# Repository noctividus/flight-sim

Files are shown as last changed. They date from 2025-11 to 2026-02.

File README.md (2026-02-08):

# Glider Joystick (Flight Simulator) — Arduino Firmware

This firmware turns a **SparkFun Pro Micro (ATmega32U4)** into a USB flight simulator HID for elevator, aileron, rudder, air brakes, and wheel brake (digital), plus a few buttons. Analog axes are read via an **ADS1015** I²C ADC to maximize resolution.

## Required Libraries

- **Arduino Joystick Library** (Matthew Heironimus) — exposes HID joystick
  - <https://github.com/MHeironimus/ArduinoJoystickLibrary>
- **SparkFun ADS1015 Arduino Library** — external 12‑bit ADC
  - <https://github.com/sparkfun/SparkFun_ADS1015_Arduino_Library>
- **Encoder** (PJRC) — quadrature encoder for wheel brake
  - <https://www.pjrc.com/teensy/td_libs_Encoder.html>
- **Wire** — built‑in I²C
- **EEPROM** — built‑in (used for calibration storage)

> Libraries referenced in code: `Joystick.h`, `SparkFun_ADS1015_Arduino_Library.h`, `Wire.h`, `EEPROM.h`, `Encoder.h`.

## MCU & Peripherals

- **MCU:** SparkFun Pro Micro (5V/16 MHz or 3.3V/8 MHz)
- **ADC:** SparkFun **ADS1015** (I²C)
  - Default gain set to `ADS1015_CONFIG_PGA_1` to avoid saturation.
- **Brake:** Quadrature **encoder** (CLK/DT)
- **Buttons:** Joystick pushbutton (active‑LOW), Brake button, Release switch

### I²C Wiring (ADS1015 ↔ Pro Micro)
> This is best accomplished using the sparkfun qwic connector.

| ADS1015 | Pro Micro | Notes |
|---|---|---|
| VCC | VCC (3.3 V or 5 V)* | Match board voltage |
| GND | GND | Common ground |
| **SDA** | **SDA** (labeled) | I²C data |
| **SCL** | **SCL** (labeled) | I²C clock |

\* The ADS1015 accepts 2–5.5 V; use the same voltage as your sensors/pots.

### Axis & Input Mapping

Analog axes are read from the ADS1015 single‑ended channels:

| Function | Code Symbol | ADS1015 Channel | Notes |
|---|---|---:|---|
| **Elevator (Pitch)** | `elevatorPinADC` | **A0 (0)** | Hall Effect Sensor → A0, other ends to VCC/GND |
| **Aileron (Roll)** | `aileronPinADC` | **A1 (1)** | Hall Effect Sensor → A1 |
| **Rudder (Yaw)** | `RUDDER_ADC_PIN` | **A2 (2)** | Hall Effect Sensor → A2 |

Digital inputs on the Pro Micro:

| Function | Code Symbol | Pro Micro Pin | Mode | Active Level |
|---|---|---:|---|---|
| **Joystick Button** | `JOYSTICK_BTN_PIN` | **D4** | `INPUT_PULLUP` | **LOW** |
| **Towhook Release** | `RELEASE_PIN` | **D8** | `INPUT_PULLUP` | **LOW** |
| **Wheel Brake** | `BRAKE_BTN_PIN` | **D9** | `INPUT` | External pull‑up/down required |
| **Air Brake Encoder CLK** | `BRAKE_CLK_PIN` | **D0** | — | Quadrature A |
| **Air Brake Encoder DT** | `BRAKE_DT_PIN` | **D1** | — | Quadrature B |
| *(Optional LED)* | `JOYSTICK_LED_PIN` | **D5** | — | Defined, not used in code |

> Note: D0/D1 are also hardware Serial (RX/TX) on the 32U4. The sketch uses `Serial`, so avoid connecting external serial devices on these pins during normal operation.

### Legacy Analog Defines

`elevatorPin A0`, `aileronPin A1`, and `rudderPin A2` are defined but **not used**; the sketch reads ADS1015 channels instead.

## Features

- USB HID joystick with Pitch, Roll, Rudder, Throttle/Brake and buttons
- On‑device **calibration**, persisted to EEPROM
- Adjustable encoder‑based brake input

## Calibration (at Power‑On)

1. **Hold the Joystick Button (D4)** while powering or resetting.
2. Move **Roll/Pitch/Rudder** to **max** positions when prompted (serial output).
3. Move them to **min** positions when prompted.
4. Release the button to save to EEPROM and start normal operation.

EEPROM addresses used (32‑bit ints each):  
Roll: `ADDR_ROLL_MAX=0`, `ADDR_ROLL_MIN=4` • Pitch: `8/12` • Rudder: `16/20` • Brake: `24/28`.

## Build & Upload

1. Install the required libraries (above) via Library Manager or from GitHub.
2. Board: **SparkFun Pro Micro** (ATmega32U4). Select correct voltage/clock.
3. Compile & upload the provided `glider-controls.ino`.
4. Verify in Windows/Mac game controller panel that axes/buttons respond.

## Pin Summary (Quick Reference)

```
#define JOYSTICK_BTN_PIN 4
#define JOYSTICK_LED_PIN 5   // defined, not used
#define RELEASE_PIN 8
#define BRAKE_BTN_PIN 9
#define BRAKE_CLK_PIN 0
#define BRAKE_DT_PIN 1

// ADS1015 channels
#define elevatorPinADC 0   // A0
#define aileronPinADC  1   // A1
#define RUDDER_ADC_PIN 2   // A2
```

## Troubleshooting

- **No axis movement:** Check ADS1015 power and I²C (SDA/SCL continuity). Ensure pots are wired as voltage dividers.
- **Axis saturates/clips:** Confirm gain = 1 in ADS1015 setup and sensor voltage matches VCC.
- **Encoder erratic:** Keep short, shielded wires; avoid using D0/D1 for other peripherals.

## Development Plan
 - Implement automatic calibration
   - Set max/min a narrow band
   - User starts every session by doing a full deflection on all flight controls
 - Add Carb Heat/Throttle/Mix/Pitch functions
 - Add Back button stick via i2c
 - Add Flaps

---

**Author:** Rich Mayfield  
**Target Board:** SparkFun Pro Micro

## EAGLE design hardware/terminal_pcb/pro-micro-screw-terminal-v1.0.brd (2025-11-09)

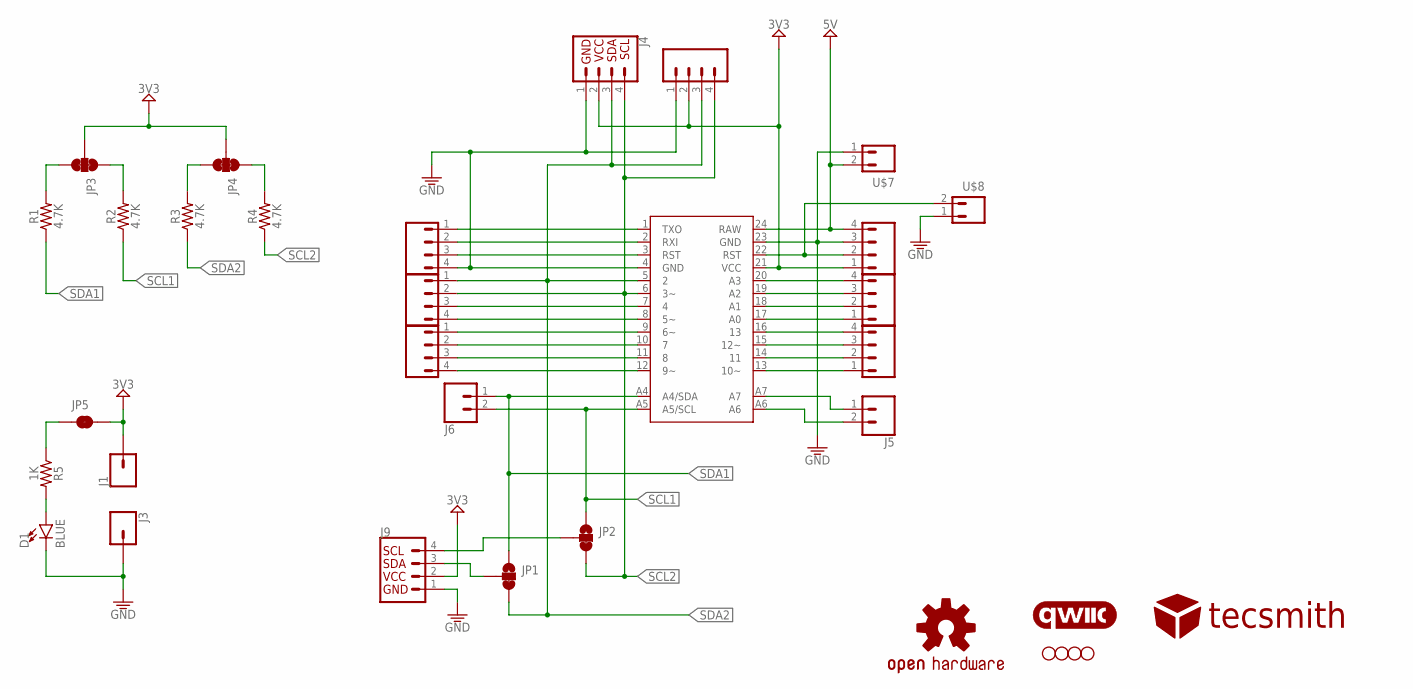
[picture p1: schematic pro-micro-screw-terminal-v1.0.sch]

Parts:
B1: ARDUINO_PRO_MININO_FTDI; ARDUINO_PRO_MINI
D1: BLUE; LED-0603
H1, H2, H5, H6: STAND-OFF
J1, J3: CONN_01PTH_NO_SILK_YES_STOP; 1X01_NO_SILK
J2: CONN_04PTH; 1X04
J4, J9: QWIIC_RIGHT_ANGLE; JST04_1MM_RA
J5, J6: CONN_02; 1X02
JP1, JP2: JUMPER-SMT_3_1-NC_TRACE_SILK; SMT-JUMPER_3_1-NC_TRACE_SILK
JP3, JP4: JUMPER-SMT_3_2-NC_TRACE_SILK; SMT-JUMPER_3_2-NC_TRACE_SILK
JP5: JUMPER-SMT_2_NC_TRACE_SILK; SMT-JUMPER_2_NC_TRACE_SILK
LOGO1: OSHW-LOGOS; OSHW-LOGO-S
LOGO2: QWIIC_LOGO_6MM; QWIIC_6MM
R1, R2, R3, R4: 4.7K; 0805
R5: 1K; 0603
U$1, U$2, U$3, U$4, U$5, U$6: CON_04SCREW; WURTH_2431_3.5MM_4X_SCREW
U$7: CON_02SCREW; WURTH_2431_3.5MM_2X_SCREW
U$8: JST-PH-2NS; JST-PH2-NO-SILK
U$9: TECSMITH-LOGO

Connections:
GND: B1.4 (GND), B1.23 (GND), D1.C, J2.1, J3.1, J4.1, J9.1, U$1.4, U$6.3, U$7.1, U$8.1
unnamed: B1.1 (TXO), U$1.1
unnamed: B1.2 (RXI), U$1.2
unnamed: B1.3 (RST), U$1.3
unnamed: B1.A7, J5.1
unnamed: B1.A6, J5.2
unnamed: D1.A, R5.2
unnamed: B1.7 (4), U$2.3
unnamed: B1.8 (5~), U$2.4
unnamed: B1.9 (6~), U$3.1
unnamed: B1.10 (7), U$3.2
unnamed: B1.11 (8), U$3.3
unnamed: B1.12 (9~), U$3.4
unnamed: JP5.1, R5.1
unnamed: B1.22 (RST), U$6.2, U$8.2
unnamed: JP3.1, R2.2
unnamed: B1.20 (A3), U$5.4
unnamed: B1.19 (A2), U$5.3
unnamed: B1.18 (A1), U$5.2
unnamed: B1.17 (A0), U$5.1
unnamed: B1.16 (13), U$4.4
unnamed: B1.15 (12~), U$4.3
unnamed: B1.14 (11), U$4.2
unnamed: B1.13 (10~), U$4.1
unnamed: JP3.3, R1.2
unnamed: JP4.3, R3.2
unnamed: JP4.1, R4.2
RAW: B1.24 (RAW), U$6.4, U$7.2
SCL: J9.4, JP2.2
SCL1: B1.A5 (A5/SCL), J6.2, JP2.1, R2.1
SCL2: B1.6 (3~), J2.4, J4.4, JP2.3, R4.1, U$2.2
SDA: J9.3, JP1.2
SDA1: B1.A4 (A4/SDA), J6.1, JP1.1, R1.1
SDA2: B1.5 (2), J2.3, J4.3, JP1.3, R3.1, U$2.1
VCC: B1.21 (VCC), J1.1, J2.2, J4.2, J9.2, JP3.2, JP4.2, JP5.2, U$6.1

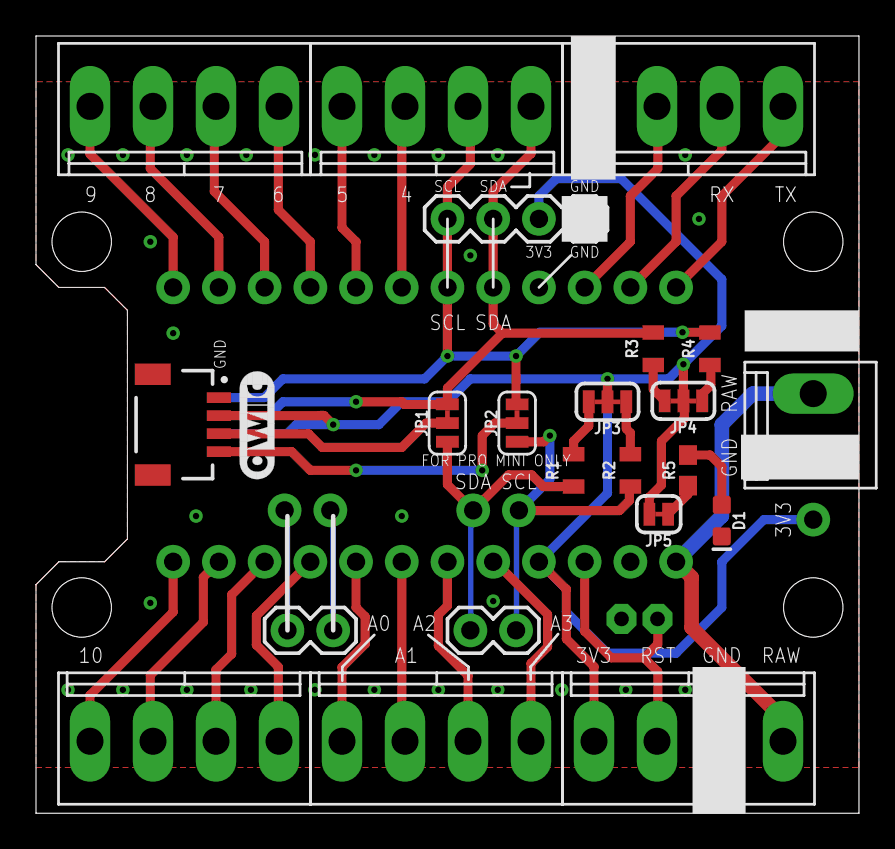
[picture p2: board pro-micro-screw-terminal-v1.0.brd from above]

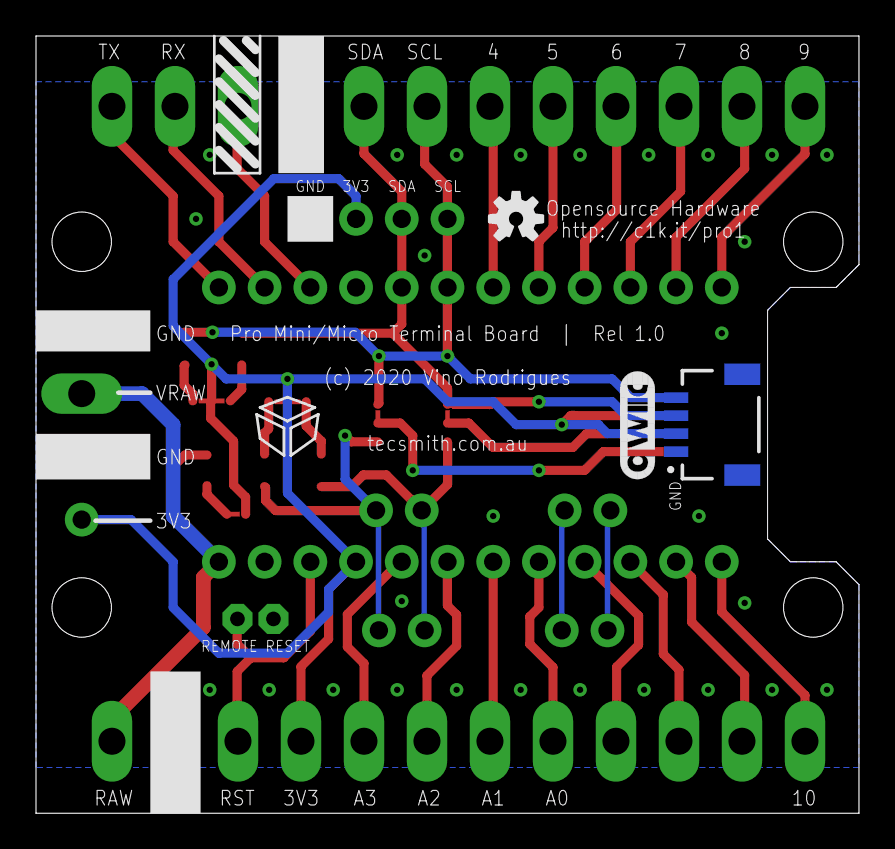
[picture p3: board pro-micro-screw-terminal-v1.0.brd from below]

Board: 2 copper layers, 45.7 x 43.2 mm, 35 parts (4 on the bottom side), 35 nets.

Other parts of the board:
LOGO3: QWIIC_LOGO_6MM; QWIIC_6MM

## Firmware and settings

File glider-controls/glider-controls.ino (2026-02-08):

// Glider Joystick Program
// Made to run on Sparkfun Pro Micro
// Rich Mayfield

#include <Joystick.h>
#include <SparkFun_ADS1015_Arduino_Library.h> //Click here to get the library: http://librarymanager/All#SparkFun_ADS1015
#include <Wire.h>
#include <EEPROM.h>
#include <Encoder.h>

#define INTERVAL 10
#define SEND_MODE false

#define elevatorPin A0
#define aileronPin A1
#define rudderPin A2

#define elevatorPinADC 0
#define aileronPinADC 1
#define RUDDER_ADC_PIN 2
#define JOYSTICK_BTN_PIN 4
#define JOYSTICK_LED_PIN 5

#define RELEASE_PIN 8
#define BRAKE_BTN_PIN 9
#define BRAKE_CLK_PIN 0
#define BRAKE_DT_PIN 1

#define ADDR_ROLL_MAX 0
#define ADDR_ROLL_MIN 4
#define ADDR_PITCH_MAX 8
#define ADDR_PITCH_MIN 12
#define ADDR_RUDDER_MAX 16
#define ADDR_RUDDER_MIN 20
#define ADDR_BRAKE_MAX 24
#define ADDR_BRAKE_MIN 28

//Time required to complete 3 rudder wags to signal a start
#define WAG_TIME 3000
#define WAG_TOLERANCE 20

ADS1015 adcSensor;
Encoder brakeEncoder(BRAKE_CLK_PIN, BRAKE_DT_PIN);

//Construct the joystick per your hardware configuration

Joystick_ Joystick(
  JOYSTICK_DEFAULT_REPORT_ID, //HID ID
  JOYSTICK_TYPE_MULTI_AXIS, //Joystick Type
  4, // # of Available Buttons
  0, // # of Hat Switches
  true,     // X Axis 
  true,     // Y Axis
  false,    // Z Axis
  false,    // X Rotation
  false,    // Y Rotation
  false,    // Z Rotation
  true,     // Rudder
  true,    // Throttle
  false,    // Accelerator
  false,     // Brake
  false     //Steering
  );   


 
uint16_t JoystickRoll;
uint16_t JoystickPitch;
uint16_t JoystickRudder;
uint16_t JoystickThrottle;
boolean  JoystickButton;
boolean Release;
boolean BrakeButton;

//Rudder Wag Detection
uint16_t rudderMax = 0;
uint16_t rudderMin = 2047;
boolean firstWag = false;
boolean secondWag = false;
boolean thirdWag = false;
boolean rudderWag = false;
boolean wagTimeout = true;
long wagTime = 0;

long previousMillis = 0;        // will store last time we went through loop

void calibrate()
{
  Serial.println("*****Calibrate Joystick*****");
  //Set inital max/min opposite values based on 11-Bit ADC range.
  //This way initally, the input will always be higher/lower than the min/max.
  uint16_t aileronMax = 0;
  uint16_t aileronMin = 2047;
  uint16_t elevatorMax = 0;
  uint16_t elevatorMin = 2047;

  uint16_t brakeMax = 0;
  uint16_t brakeMin = 2047; 

  //Loop as long as button is held
  while( !digitalRead(JOYSTICK_BTN_PIN) )
  {
    //Read Control Inputs
    JoystickRoll = adcSensor.getSingleEnded(aileronPinADC); 
    JoystickPitch = adcSensor.getSingleEnded(elevatorPinADC); 
    JoystickRudder = adcSensor.getSingleEnded(RUDDER_ADC_PIN);

     //Check for max/min values for each control input.
    if(JoystickRoll>aileronMax) aileronMax = JoystickRoll;
    if(JoystickRoll<aileronMin) aileronMin = JoystickRoll;

    if(JoystickPitch>elevatorMax) elevatorMax = JoystickPitch;
    if(JoystickPitch<elevatorMin) elevatorMin = JoystickPitch;

    if(JoystickRudder>rudderMax) rudderMax = JoystickRudder;
    if(JoystickRudder<rudderMin) rudderMin = JoystickRudder;

    if(JoystickThrottle>brakeMax) brakeMax = JoystickThrottle;
    if(JoystickThrottle<brakeMin) brakeMin = JoystickThrottle;
    delay(10);  
  }

  //Finished Calibrating
  Serial.println("Calibration Complete");
  Serial.println(aileronMin);
  Serial.println(aileronMax);
  Serial.println(elevatorMin);
  Serial.println(elevatorMax);
  Serial.println(rudderMin);
  Serial.println(rudderMax);

  //Finished calibration, set Joystick Object Max/Min Values
  Joystick.setXAxisRange(aileronMin, aileronMax);
  Joystick.setYAxisRange(elevatorMin, elevatorMax);
  Joystick.setRudderRange(rudderMin, rudderMax);
  Joystick.setThrottleRange(brakeMin, brakeMax);

  //Save calibration data to EEPROM
   EEPROM.put(ADDR_ROLL_MAX, aileronMax);
   EEPROM.put(ADDR_ROLL_MIN, aileronMin);
      
   EEPROM.put(ADDR_PITCH_MAX, elevatorMax);
   EEPROM.put(ADDR_PITCH_MIN, elevatorMin);
   
   EEPROM.put(ADDR_RUDDER_MAX, rudderMax);
   EEPROM.put(ADDR_RUDDER_MIN, rudderMin);
   
   EEPROM.put(ADDR_BRAKE_MAX, brakeMax);
   EEPROM.put(ADDR_BRAKE_MIN, brakeMin);
   Serial.println("*****Calibration written to EEPROM*****");
}

void setup() 
{
  //Set Arduino Pin Modes
  pinMode(JOYSTICK_BTN_PIN, INPUT_PULLUP);
  pinMode(RELEASE_PIN, INPUT_PULLUP);
  pinMode(BRAKE_BTN_PIN, INPUT);
  
  Wire.begin();
  Serial.begin(115200);
  delay(3000); //Wait for serial connection to start
  Serial.println("Joystick Code");
  
  if (adcSensor.begin() == true)
  {
    Serial.println("Device found. I2C connections are good.");
    adcSensor.setGain(ADS1015_CONFIG_PGA_1); //Sets the Gain/FSR to 1 so we don't saturate
  }
  else
  {
    Serial.println("External ADC not found. Check wiring.");
    while (1); // stall out forever
  }

  //Check to see if the joystick button is pressed, if so, run the calibration function use this- !digitalRead(JOYSTICK_BTN_PIN)
  if( false )
    {
      Serial.println("Running Calibration");
      calibrate();
    }else
        {
          Serial.println("Using previously stored calibration");
            uint16_t aileronMax = 1615;
            uint16_t aileronMin = 15;
            uint16_t elevatorMax = 1615;
            uint16_t elevatorMin = 15;
            rudderMax = 1615;
            rudderMin = 15;
            uint16_t brakeMax = 1615;
            uint16_t brakeMin = 15;
            
            Joystick.setXAxisRange(aileronMin, aileronMax);
            Joystick.setYAxisRange(elevatorMin, elevatorMax);
            Joystick.setRudderRange(rudderMin, rudderMax);
            Joystick.setThrottleRange(brakeMin, brakeMax);
        }
  
  // Initialize Joystick Library
  Joystick.begin(SEND_MODE);  //Start Emulator
}

void loop() 
{
  // Read Joystick
  JoystickRoll = adcSensor.getSingleEnded(aileronPinADC); 
  JoystickPitch = adcSensor.getSingleEnded(elevatorPinADC); 
  
  // Read Rudder Pedals
  JoystickRudder = adcSensor.getSingleEnded(RUDDER_ADC_PIN); 

  // Read Brake (Rotary Encoder)
  JoystickThrottle = brakeEncoder.read();

  //Read Digital Inputs
  JoystickButton = !digitalRead(JOYSTICK_BTN_PIN);
  Release = digitalRead(RELEASE_PIN);
  BrakeButton= digitalRead(BRAKE_BTN_PIN);

  //Code to check for a rudder wag
  //Check for timeout
  if(wagTime + WAG_TIME > millis())
  {
    wagTimeout = false;
  }else
    {
      wagTimeout=true;
    }
   
  if(JoystickRudder>rudderMax-WAG_TOLERANCE)
  {
    firstWag= true;
    wagTimeout= false;
    wagTime = millis();
  }
  if(JoystickRudder<rudderMin + WAG_TOLERANCE && firstWag && !wagTimeout) 
  {
    Serial.print("Wag 3");
    secondWag = true;
  }
  if(JoystickRudder>rudderMax - WAG_TOLERANCE && secondWag && !wagTimeout) rudderWag = true;

  //Reset Wag if time expired
  if(wagTimeout)
  {
    firstWag = false;
    secondWag = false;
    wagTime = 0;
    rudderWag = false;
  }


  
  // Output Controls
  Joystick.setXAxis(JoystickRoll);
  Joystick.setYAxis(JoystickPitch);
  Joystick.setRudder(JoystickRudder);
  Joystick.setThrottle(JoystickThrottle);
  Joystick.setButton(0,JoystickButton);
  Joystick.setButton(1,rudderWag);
  Joystick.setButton(2, Release);
  Joystick.setButton(3, BrakeButton);
  
  //Wait for interval
  while(millis() - previousMillis < INTERVAL)
    {
    }
  previousMillis=millis();
  
  Serial.print("Millis: ");
  Serial.println(previousMillis);
  Serial.print("Aileron: ");
  Serial.println(JoystickRoll);
  Serial.print("Elevator: ");
  Serial.println(JoystickPitch);
  Serial.print("Rudder: ");
  Serial.println(JoystickRudder);
  Serial.print("Throttle/Brake: ");
  Serial.println(JoystickThrottle);
  Serial.print("Button 0: ");
  Serial.println(JoystickButton);
  Serial.print("Button 1: ");
  Serial.println(rudderWag);
  Serial.println();
  
  //Send Update
  Joystick.sendState();
} 

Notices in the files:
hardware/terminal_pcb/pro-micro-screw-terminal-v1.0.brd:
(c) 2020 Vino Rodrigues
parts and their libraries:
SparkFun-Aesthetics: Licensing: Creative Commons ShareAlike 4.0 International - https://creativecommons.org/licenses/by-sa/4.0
